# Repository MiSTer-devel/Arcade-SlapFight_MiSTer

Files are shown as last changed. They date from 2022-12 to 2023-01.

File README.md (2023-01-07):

<h1># SLAP FIGHT / ALCON</H1>
A big thank you to Neil Ward for providing a set of preliminary schematics and a diagnostic ROM.

Thank you to the following members of the MiSTer community: Boogermann, misterretrowolf, Sorgelig, Jotego, JimmyStones, Kitrinx & BirdyBro.

Slap Fight was developed by Toaplan and released by Taito in 1986. Slap Fight was known as ALCON (Alien League Of Cosmic Nations)

<h2>Compatible Platforms</h2>
<li>MiSTer FPGA</li>

<h2>Compatible Games</h2>
<blockquote>
<p dir="auto"><strong>ROMs NOT INCLUDED:</strong> By using this core you agree to provide your own roms.</p>
</blockquote>

<li>Slap Fight</li>
<li>Tiger Heli</li>
<li>Get Star</li>

<h2>Partially Working</h2>
<li>Performan</li>

<h2>Game Instructions:</h2>

	The year is 2059.  Aliens have overrun the planet.  The Allied League of Cosmic Nations, commonly called ALCON, have convened to combat this menace to the world.  ALCON has determined that a sole, experienced pilot, flying the experimental SW475 aircraft, must defend the world against certain destruction.

	YOU are the pilot that must fly the SW475 aircraft and defeat the aliens.

<h2>Maneuvers:</h2>

	Use the joystick to fly the SW475 over the terrain.
	Use 'Fire' button to shoot at enemies.
	Use 'Weapon Select' button to choose your weapons.
	The 'Weapon's Gauge' on the bottom of the screen shows which weapons can be used (the wording on the weapons turn yellow).
	Pick up starts to advance 'Weapon's Gauge'

<h2>Weapons available on the SW475:</h2>

	SPEED  - This will increase you flying speed
	SHOT   - Normal forward fire
	SIDE   - Right and Left fire
	WING   - Double, Triple and Quadruple fire power
	BOMB   - Wide range fire
	LASER  - Long range fire
	H. MIS - Homing missiles
	SHIELD - Indestructible against three hits

<h2>DIP Switch Settings:</h2>

	Cabinet Type       - Up-Right* ,Table
	Screen			   - Normal*, Invert
	Mode			   - Normal Game*, Screen Test Mode
	Demo Sounds		   - ON*, OFF 
	Coinage            - 1 Coin/1 Play*, 1 Coin/2 Play, 2 Coins/1 Play, 2 Coins/3 Play
	Difficulty         - A, B*, C, D
	Extend             - 30000 Every 100000*, 50000 Every 200000, 50000 Only, 100000 Only
	Fighter Count      - 1,2,3* & 5
	Dip Switch Display - OFF*, ON (show dip switch configuration) 

	*Factory Setting

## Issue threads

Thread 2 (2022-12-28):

Over hdmi has weird scaling issues and shimmering

Spazmoid1981, 2022-12-28:
Looks like the resolution is wrong or the video processing over hdmi is not correctly sized - also adding any video filter results in some weird shimmering over the screen

paulb-nl, 2022-12-31:
The `ce_pix` signal is generated incorrectly. Just output `pixel_clk` from slapcore.v and connect it directly to ce_pix and the `arcade_video` module will handle the rest.

https://github.com/MiSTer-devel/Arcade-SlapFight_MiSTer/blob/10bae8e3ea879105e4ef7865437a0482ff7a11ab/rtl/slapcore.v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

antongale, 2022-12-31:
> The `ce_pix` signal is generated incorrectly. Just output `pixel_clk` from slapcore.v and connect it directly to ce_pix and the `arcade_video` module will handle the rest.
>
> https://github.com/MiSTer-devel/Arcade-SlapFight_MiSTer/blob/10bae8e3ea879105e4ef7865437a0482ff7a11ab/rtl/slapcore.v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

Thank you for bringing this to my attention.  The core has been updated to bring the pixel_clk into arcade video.

Spazmoid1981, 2022-12-31:
Thanks guys - awesome - happy new year to all

Regards,
Michael Johnson
07976400758

On 31 Dec 2022, at 18:58, Anton Gale ***@***.***> wrote:

Closed #2<https://github.com/MiSTer-devel/Arcade-SlapFight_MiSTer/issues/2> as completed.

—
Reply to this email directly, view it on GitHub<https://github.com/MiSTer-devel/Arcade-SlapFight_MiSTer/issues/2#event-8132960947>, or unsubscribe<https://github.com/notifications/unsubscribe-auth/AUY442Q4PYKM4IUPOSNHM2TWQB63RANCNFSM6AAAAAATLTVGPQ>.
You are receiving this because you authored the thread.Message ID: ***@***.***>

Closed 2022-12-31.

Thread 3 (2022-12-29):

unable to flip screen for Tate mode when using CCW Tate orientation

konradpop, 2022-12-29:
flip screen option not available which is required when using a CCW tate screen

capitaineflam25, 2022-12-31:
Thanks for pointing the issue, my CRT is also CCW

antongale, 2022-12-31:
I am aware of the issue regarding the menu being missing.  An update will be released shortly.

antongale, 2022-12-31:
A new update has been pushed,  Rotation is only available over HDMI.  If you wish to flip the screen on a CRT use the DIP switch INVERT option.

Closed 2022-12-31.

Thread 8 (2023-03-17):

Slapfight sound issue

stiegis, 2023-03-17:
Don´t know if anyone experiences the same problem with the game

There is a weird sound issue going on i.e. sound only plays in mono and fades out after some time

Sound effects such as shooting etc. are not present sometimes

Also after the last update there is a missing line going through the sprites

Made a complete fresh setup in Mister but can reproduce these issues time and again

antongale, 2023-03-17:
Which update are you talking about?  Yesterdays?

stiegis, 2023-03-17:
Hello!

I am talking about the new rbf core - I made an update today and I noticed some graphics glitches in the sprites

The sound issue was BEFORE the new core update and has got nothing to do with it

P.S: I cannot be wrong about the sound issue because I compared it with the original pcb and the mister slap fight presentation

on you tube - perhaps it is my setup  it only plays in mono and somehow there are missing sounds (not polyphonic)

This is just an observation of mine - wonder if it is the same with other Mister users but I can only say that all the other

cores work perfectly fine on my mister setup. And that is the reason what makes it so weird

regards,

stiegis, 2023-03-17:
Oh I forgot something important - the graphics glitches were not present with the former rbf core

regards,
Alex

sorgelig, 2023-03-18:
Usually such issues happens when core has async clocks. Besides many async clocks, this core has several latches - another source of instability.
So core may have different kinds of issues in each build regardless what has been changed (like unrelated changes in framework affected the core work).

birdybro, 2023-03-19:
It looks like the core has a lot of async logic like sorgelig said. I looked into this after MikeS let me know. In one spot for sprite position, the output of a combinatorial block within a TTL module is being used as a clock for edge detection in a sequential block. These kinds of bugs will change from build to build without quartus giving any timing errors because so many of these are not clocked.

stiegis, 2023-03-20:
Hi!

Thanks sorgelig and birdybro

I highly appreciate your work

This was highly interesting - to find where those problems are located is probably much more difficult than to write the code

in the first place. On a hardware level when you try to fix a pcb you have to know the whole system - otherwise you will not

find the culprit. But with mister we are talking about a huge complex environment nearly unmanageable where so many

things can change. Its like comparing one drop of water with the ocean

regards

antongale, 2023-03-20:
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

Thank you for the insight, I'm still learning so I definitely don't take these comments as an insult.  I'll admit I don't know how to make this logic synchronous while retaining the rising edge detection.  The triggers are clocked with the pixel_clk.  Any insight would be helpful.

birdybro, 2023-03-20:
I'm not as far along as you are in the learning process for sure.

Given that your master clock is 36MHz, my personal way of writing the logic you laid out would be like this:

```sv
always @(posedge master_clk) begin
	if (SPR_LAT_VPOS) SPR_VPOS_D      <= SPRITE_RAM_D;	//S2_U1H
	if (SPR_LAT_INDX) SPR_IDX_D[7:0]  <= SPRITE_RAM_D;	//S2_U1J
	if (SPR_LAT_HPOS) SPR_HPOS_D[7:0] <= SPRITE_RAM_D;	//S2_U1L
	if (SPR_LAT_XDAT) begin 				//S2_U1K
		SPR_HPOS_D[8]	          <=SPRITE_RAM_D[0];
		SPR_IDX_D[9:8]	          <=SPRITE_RAM_D[7:6];
		SPR_EXT_D                 <=SPRITE_RAM_D;
	end
end
```

Not sure if this will work, doing this blind, compiling now...

Here test it out see if that resolves the issue:

[SlapFight_20230319.zip](https://github.com/MiSTer-devel/Arcade-SlapFight_MiSTer/files/11014155/SlapFight_20230319.zip)

If it did, then that's randomly what it was, but I'm just guessing.

stiegis, 2023-03-20:
Hello birdybro!

Thanks for giving this a go. I tried the last core 20230320 but did not solve the issue. Sound problem is still the same and the graphics are completely messed up now. Perhaps one has to adapt the mra file as well?

regards,
Alex

birdybro, 2023-03-20:
Nah, it's because I just blindly did this without knowing much about the core. The clocks I tied things to were probably wrong, and I probably didn't handle the uninitialized states correctly. Antongale knows the OG hardware better than anyone I think so he'll have to fix it.

antongale, 2023-03-20:
I'll fix it when I have time.  I'd rather roll back the changes and apply them, I'm aware of timing issues as I had them when originally developing the core.  Can you send me a screenshot as it will tell me exactly what the issue is.

birdybro, 2023-03-20:
There are other ways to address multiple asynchronous clocks, but it will have ot match the PCB logic that you are referencing to not break stuff the way I just did :P -

1. Use a small FIFO where crossed clock domains are occurring that might be causing improperly timed reads during writes --> https://github.com/MiSTer-devel/Arcade-TropicalAngel_MiSTer/blob/master/Arcade-TropicalAngel.sv#L344-L347 - this kind of thing might help with the sound issue if it's not already implemented.
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
2. Change some of these always blocks which use a non-clock in the sensitivity list to regular assign statements with ternaries to make them combinatorial where you are allowed to have an off-state for the signal default to 0 or something else. (e.g. `always @(posedge colour_copy) FG_PX_D[7:2]<=FG_RAMD[15:10];` --> `assign FG_PX_D[7:2]<= colour_copy ? FG_RAMD[15:10] : 6'd0`)
3. Convert inferred clocks (usually from dividers and counters) that are driving a latch (avoid latches anyways imo) or that is driving a register that is being used as a clock (in a sensitivity list of an always block)... into explicit clocks in the PLL wizard.
4. To avoid crossed clock domains in the first place, make sure that your clocks have even common division with one another, in the case of this core you have 36.0MHz, 37.93(actual 37.894736)MHz, 3.0MHz, 12.0MHz, and 72.0MHz. If you are driving logic off of outclk0/2/3/4 and you need to read/write data that is driven off of outclk1, then you will probably run into marginal timing issues.

stiegis, 2023-03-20:
Hello birdybro!

Oh my god. I thought that this stuff is not simple but this sounds to me like Chinese. Now I understand how deep this stuff goes - I don´t know how many scripts you need for a single core but to make it work at least 90% is a miracle at the end, You and the other programmers must be genius and one of a kind. If this works out fine otherwise its a good learning process.
But it is legit to point out where things can be improved
regards,

Alex

birdybro, 2023-03-20:
I'm not good at this stuff, I've only ported cores from MiST and fixed very minor things. I'm jealous of people like sorgelig and antongale who can build big complex systems up from very little.

antongale, 2023-03-21:
I've deleted the recent release SlapFight_20221231.rbf is still present and works.  I am looking into the timing issues now

antongale, 2023-03-21:
The line is now removed from the sprites.  I have played with the sound a little bit, but if anyone can help me figure out what I'm doing wrong with my JT49 implementation I'd appreciate it.  I've tried mimicking the 1942 core, but I get silence.

birdybro, 2023-03-21:
It looks like you disconnected the sound in the emu module:

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

birdybro, 2023-03-21:
Maybe @jotego would be willing to help.

jotego, 2023-03-21:
Here are my two cents.
It sounds that you need to re-design the core to make it synchronous. Just make JT49 use the same clock source as the CPU and generate a clock enable signal so the effective clock matches the one in the PCB. The clock enable signal should only be high for a single clock period.
If that doesn't make sense, I don't think I can help you.

antongale, 2023-03-21:
>  The clock enable signal should only be high for a single clock period. If that doesn't make sense, I don't think I can help you.

I think you've just given me an answer I've been searching for and looking at 'jtframe_cenxx.v' I understand what I've potentially been doing wrong.

antongale, 2023-03-22:
I've updated the clock generation to use logic almost identical to the jtframe_cen code.  I will update the code to be more synchronous, but the current build seems a lot more resilient to code changes.  The single clock period hint @jotego mentioned earlier was the key to getting jt49 to use the clk_en signal.

I still can't get the jtframe_fir part of the filter to work, so I'm still doing something wrong, but this definitely feels like progress.

jotego, 2023-03-22:
Exactly, it nots the frequency of the clock enable what matters per se, it's the number of cycles per second of the `clk & clk_en` signal. So jt49 was probably getting a much higher effective frequency than what you needed. I'm glad it's working for you now.

stiegis, 2023-03-22:
Hi!

Just tried out the new version and everything seems to work fine.

Sprite issues solved and music also ok

Thanks so much guys for working this out!! You are amazing

regards,

Alex

antongale, 2023-03-23:
Added Audio Pause to the core and utilized synchronous Z80 (T80s) for the audio CPU.  Sound glitching seems to be gone.

Closed 2023-03-23.

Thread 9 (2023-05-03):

Sound Error

harlock74, 2023-05-03:
Hi there,
When SlapFight boots up I get a Sound Error message. I have tried to press reset a few times but to no avail.
Many thanks!

birdybro, 2024-06-03:
Go into pause options and disable the pause on OSD, hit reset, and try again. The core pause seems unstable in it's current implementation.

harlock74, 2024-06-03:
Hi,
Thanks for your feedback. Unfortunately that didn't work for me.
It so weird that I don't have this issue on my second Mister setup.
Thanks anyways for your help.

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

christ776, 2024-07-23:
Hi, I'm having the same issue as well, and the workaround didn't work for me.

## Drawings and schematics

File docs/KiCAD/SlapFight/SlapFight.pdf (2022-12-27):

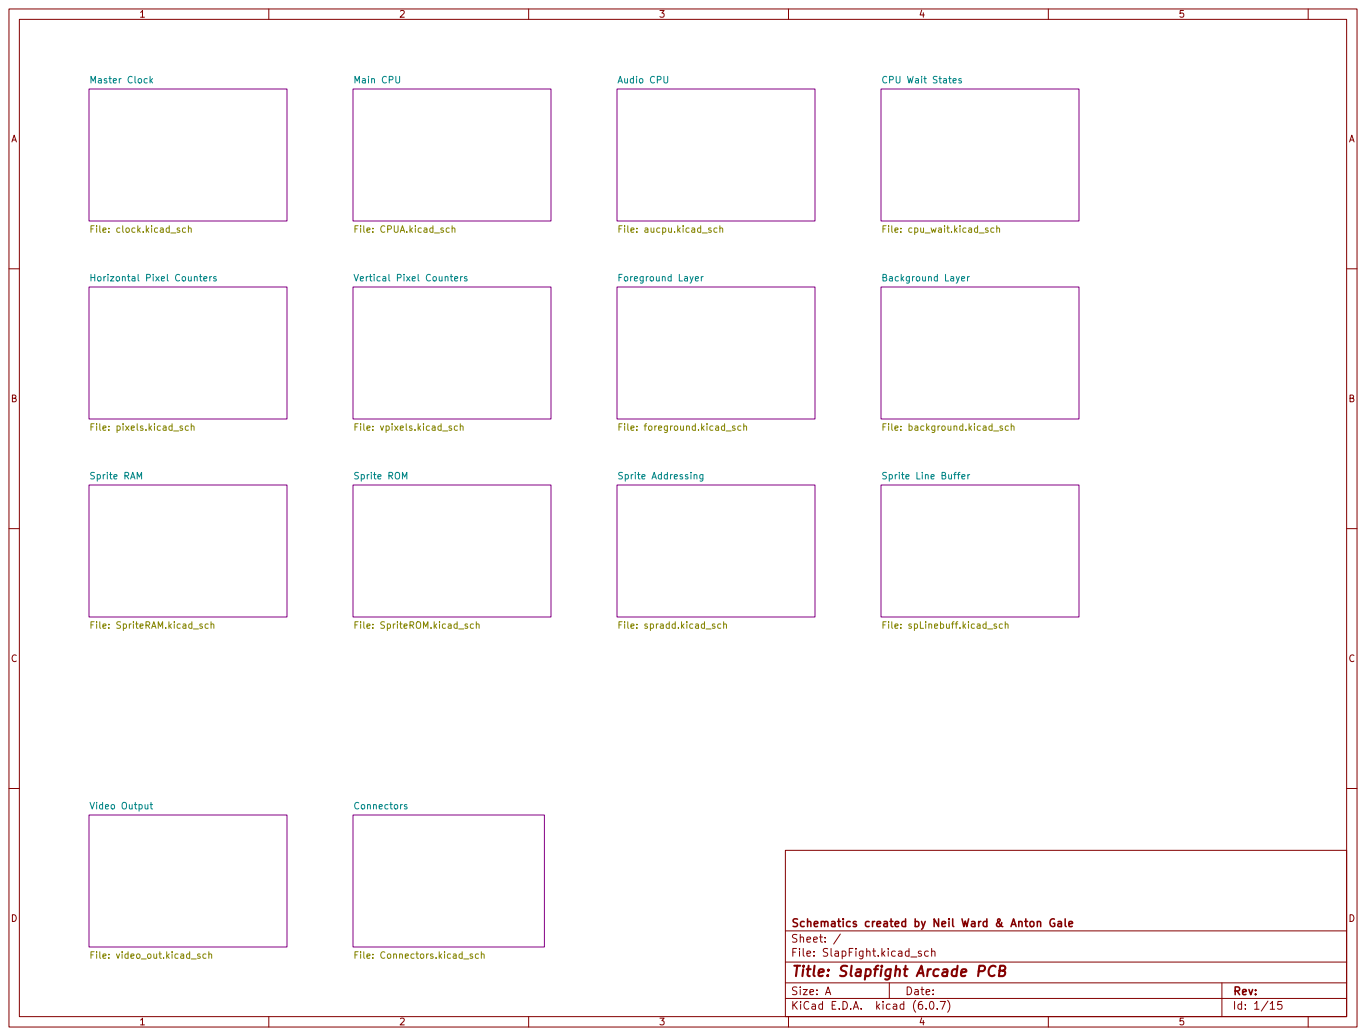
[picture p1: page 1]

CPU Wait States File: cpu_wait.kicad_sch Vertical Pixel Counters File: vpixels.kicad_sch

Horizontal Pixel Counters File: pixels.kicad_sch

File: SlapFight.kicad_sch Sheet: / Schematics created by Neil Ward & Anton Gale

Id: 1/15 Title: Slapfight Arcade PCB

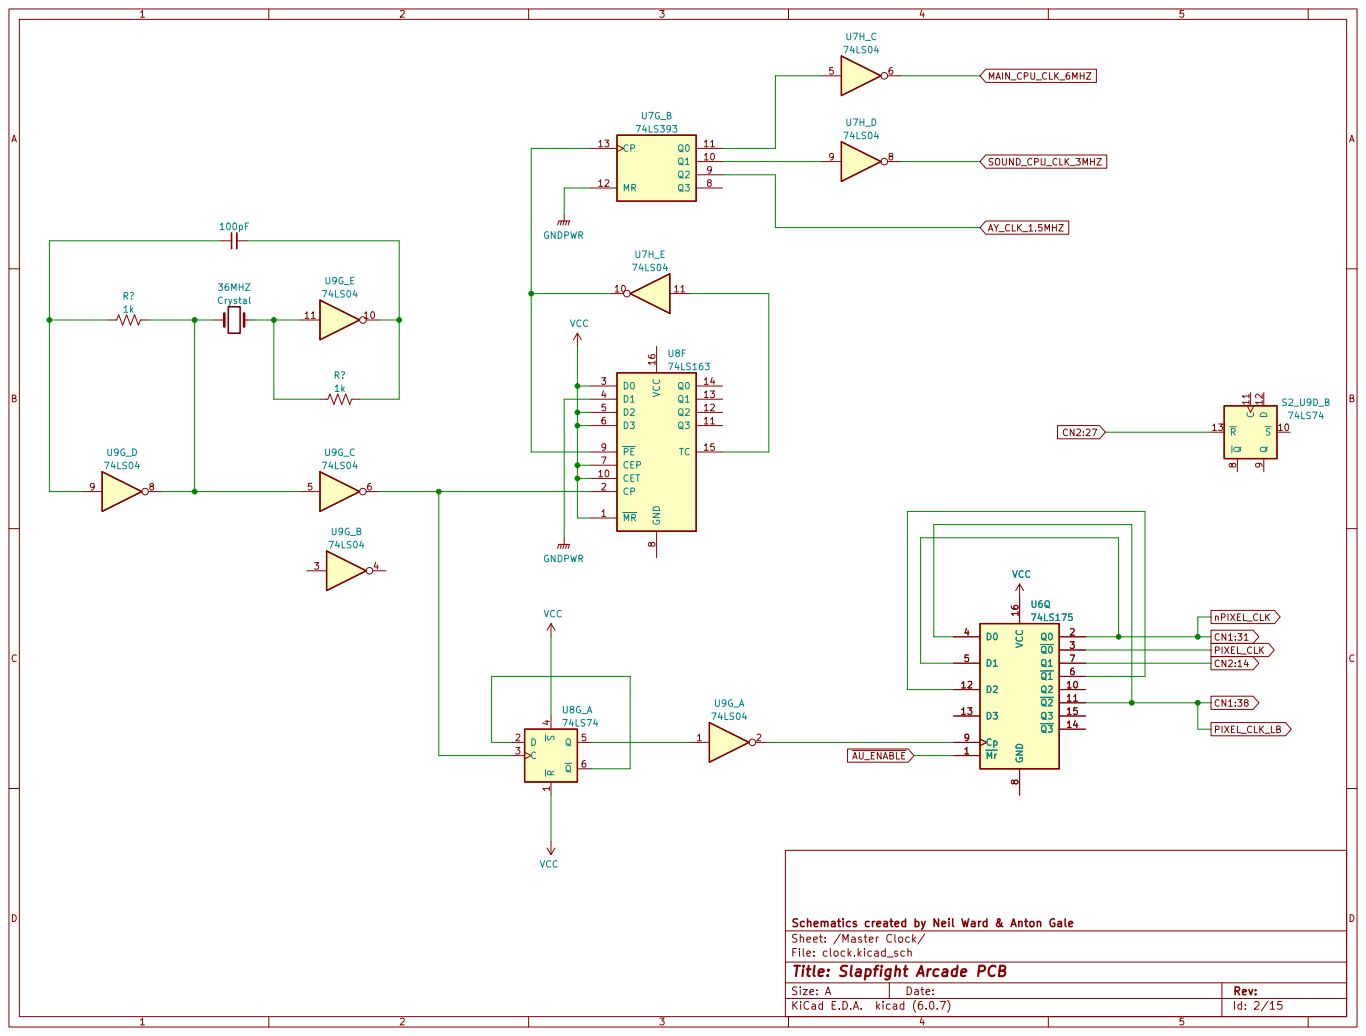
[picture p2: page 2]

File: clock.kicad_sch Sheet: /Master Clock/ Schematics created by Neil Ward & Anton Gale

Id: 2/15 Title: Slapfight Arcade PCB

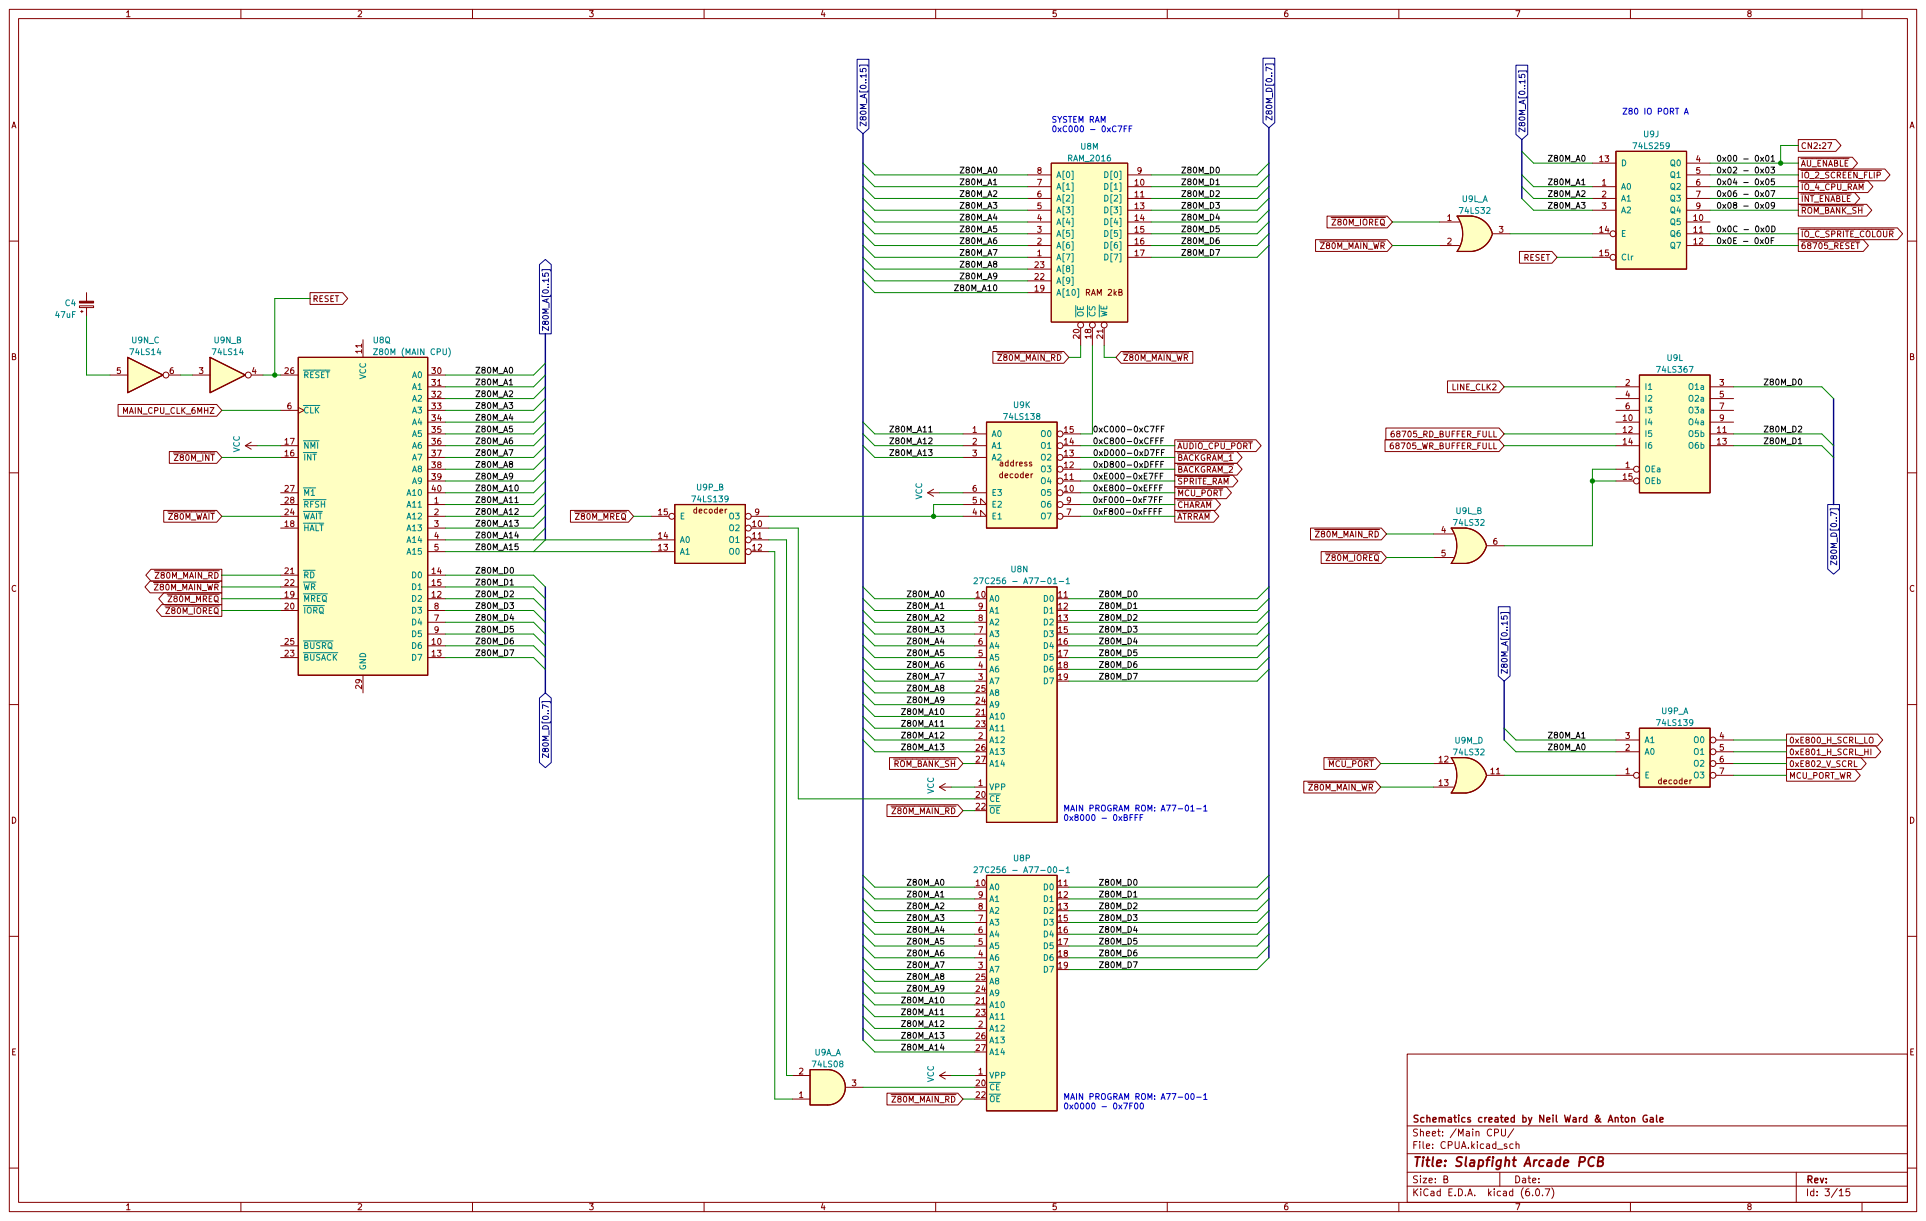
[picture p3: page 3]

Id: 3/15 Title: Slapfight Arcade PCB

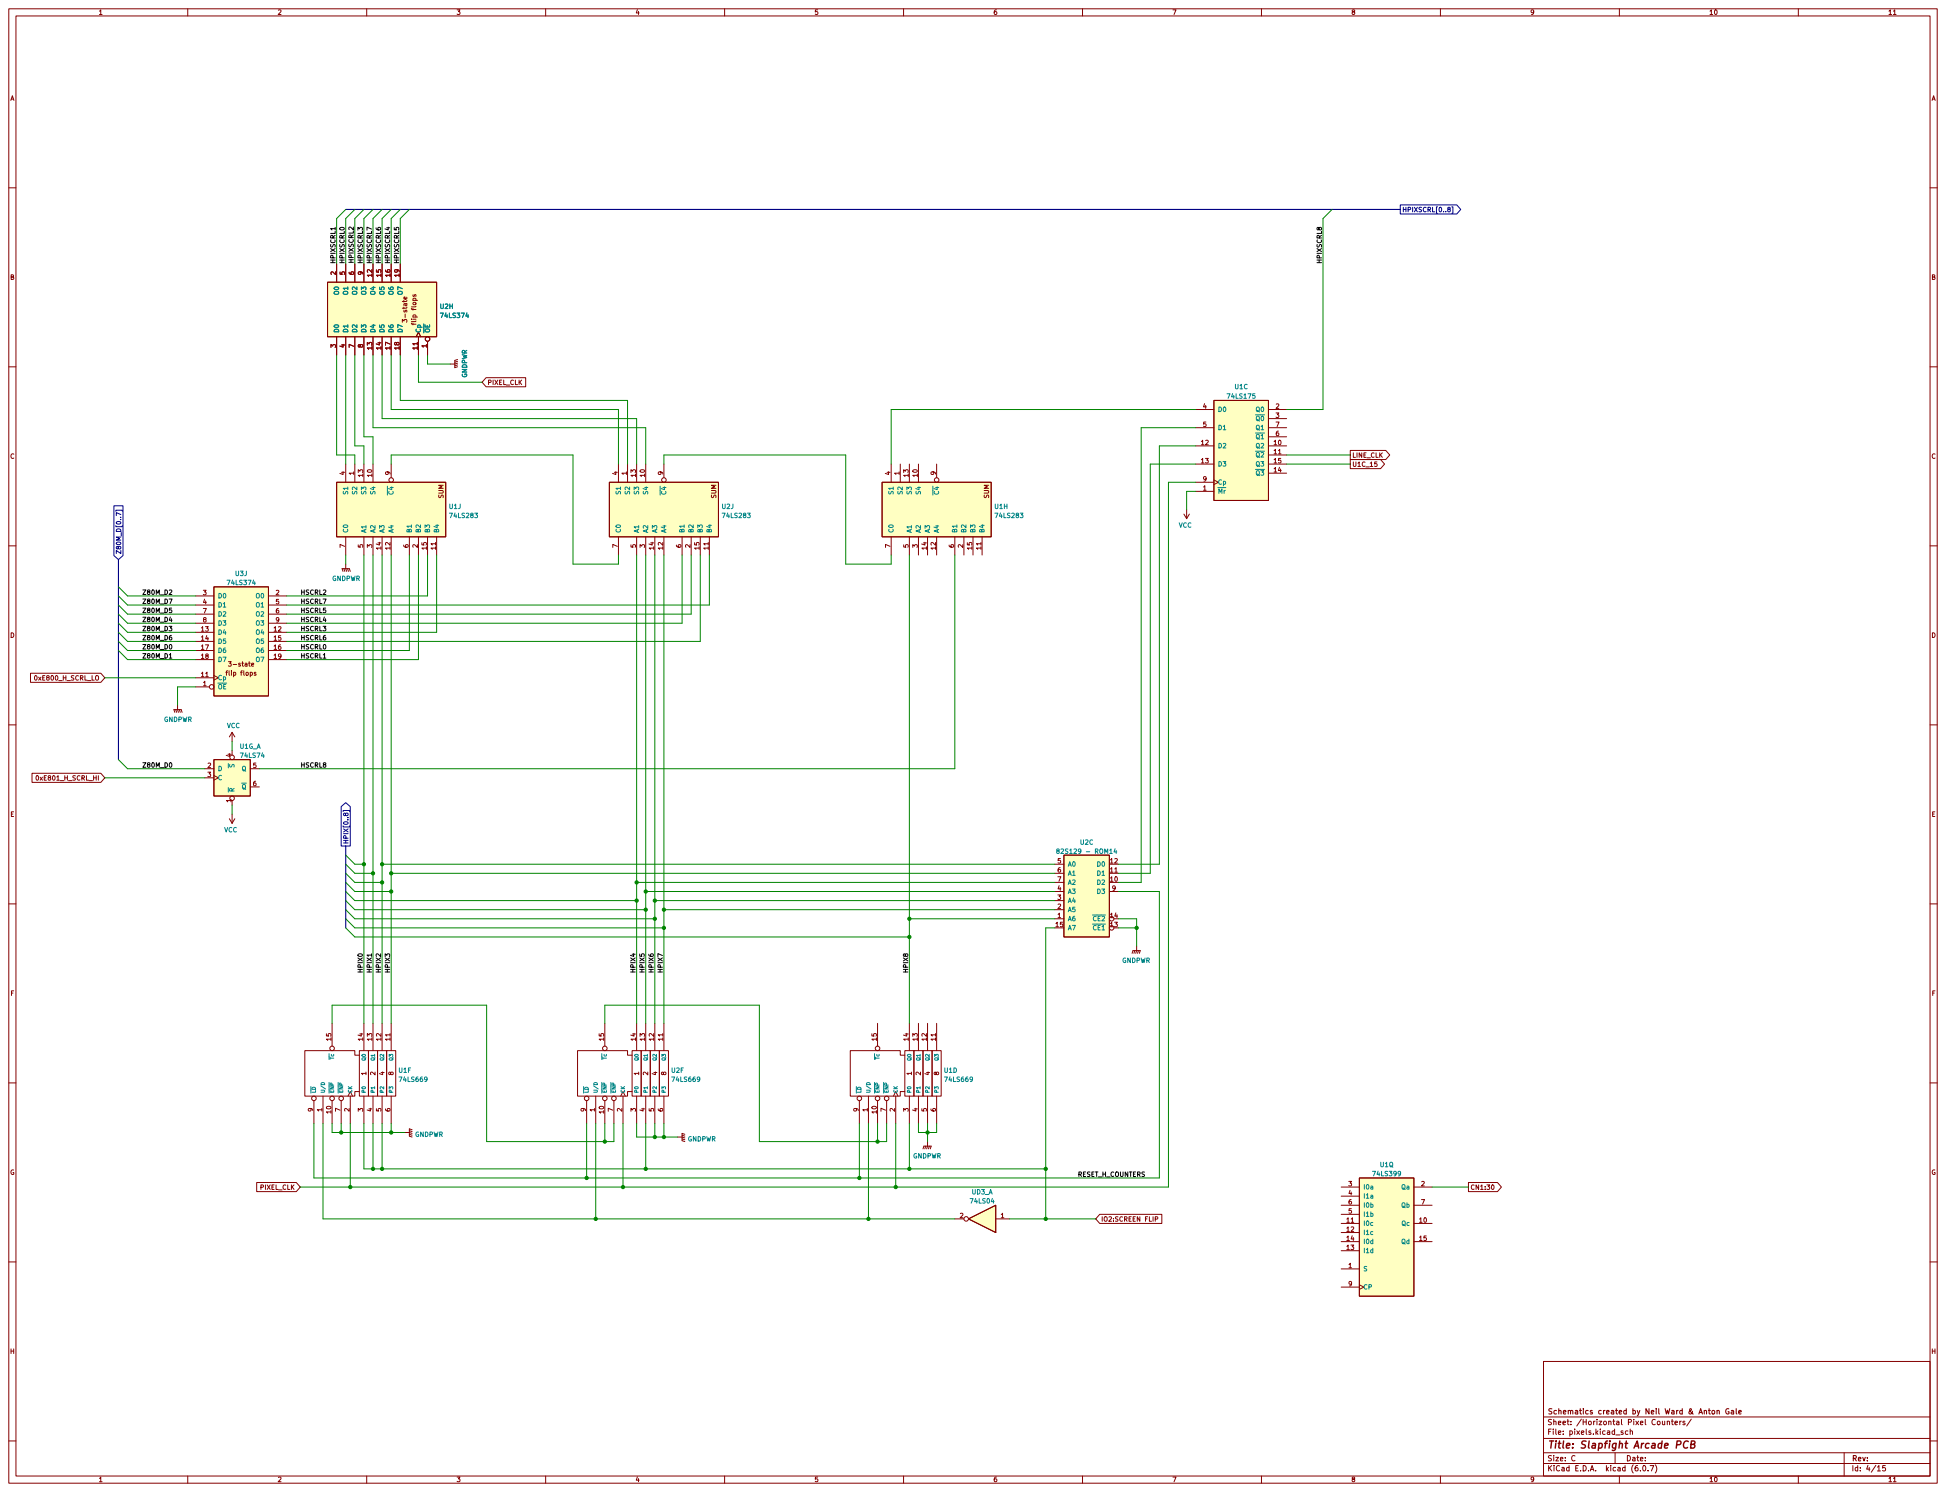
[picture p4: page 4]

File: pixels.kicad_sch Sheet: /Horizontal Pixel Counters/ Schematics created by Neil Ward & Anton Gale GNDPWRSUMS2

1 ~{ENP} 10 Q3 11 Q2 12 Q1 13 Q0 14 ~{Tc} 15 CK 2 P0 3 P1 4 P2 5 P3 6 ~{ENP} 7 ~{LD} 9 U1F

1 ~{ENP} 10 Q3 11 Q2 12 Q1 13 Q0 14 ~{Tc} 15 CK 2 P0 3 P1 4 P2 5 P3 6 ~{ENP} 7 ~{LD} 9 U2F

1 ~{ENP} 10 Q3 11 Q2 12 Q1 13 Q0 14 ~{Tc} 15 CK 2 P0 3 P1 4 P2 5 P3 6 ~{ENP} 7 ~{LD} 9 U1D

Id: 4/15 Title: Slapfight Arcade PCB

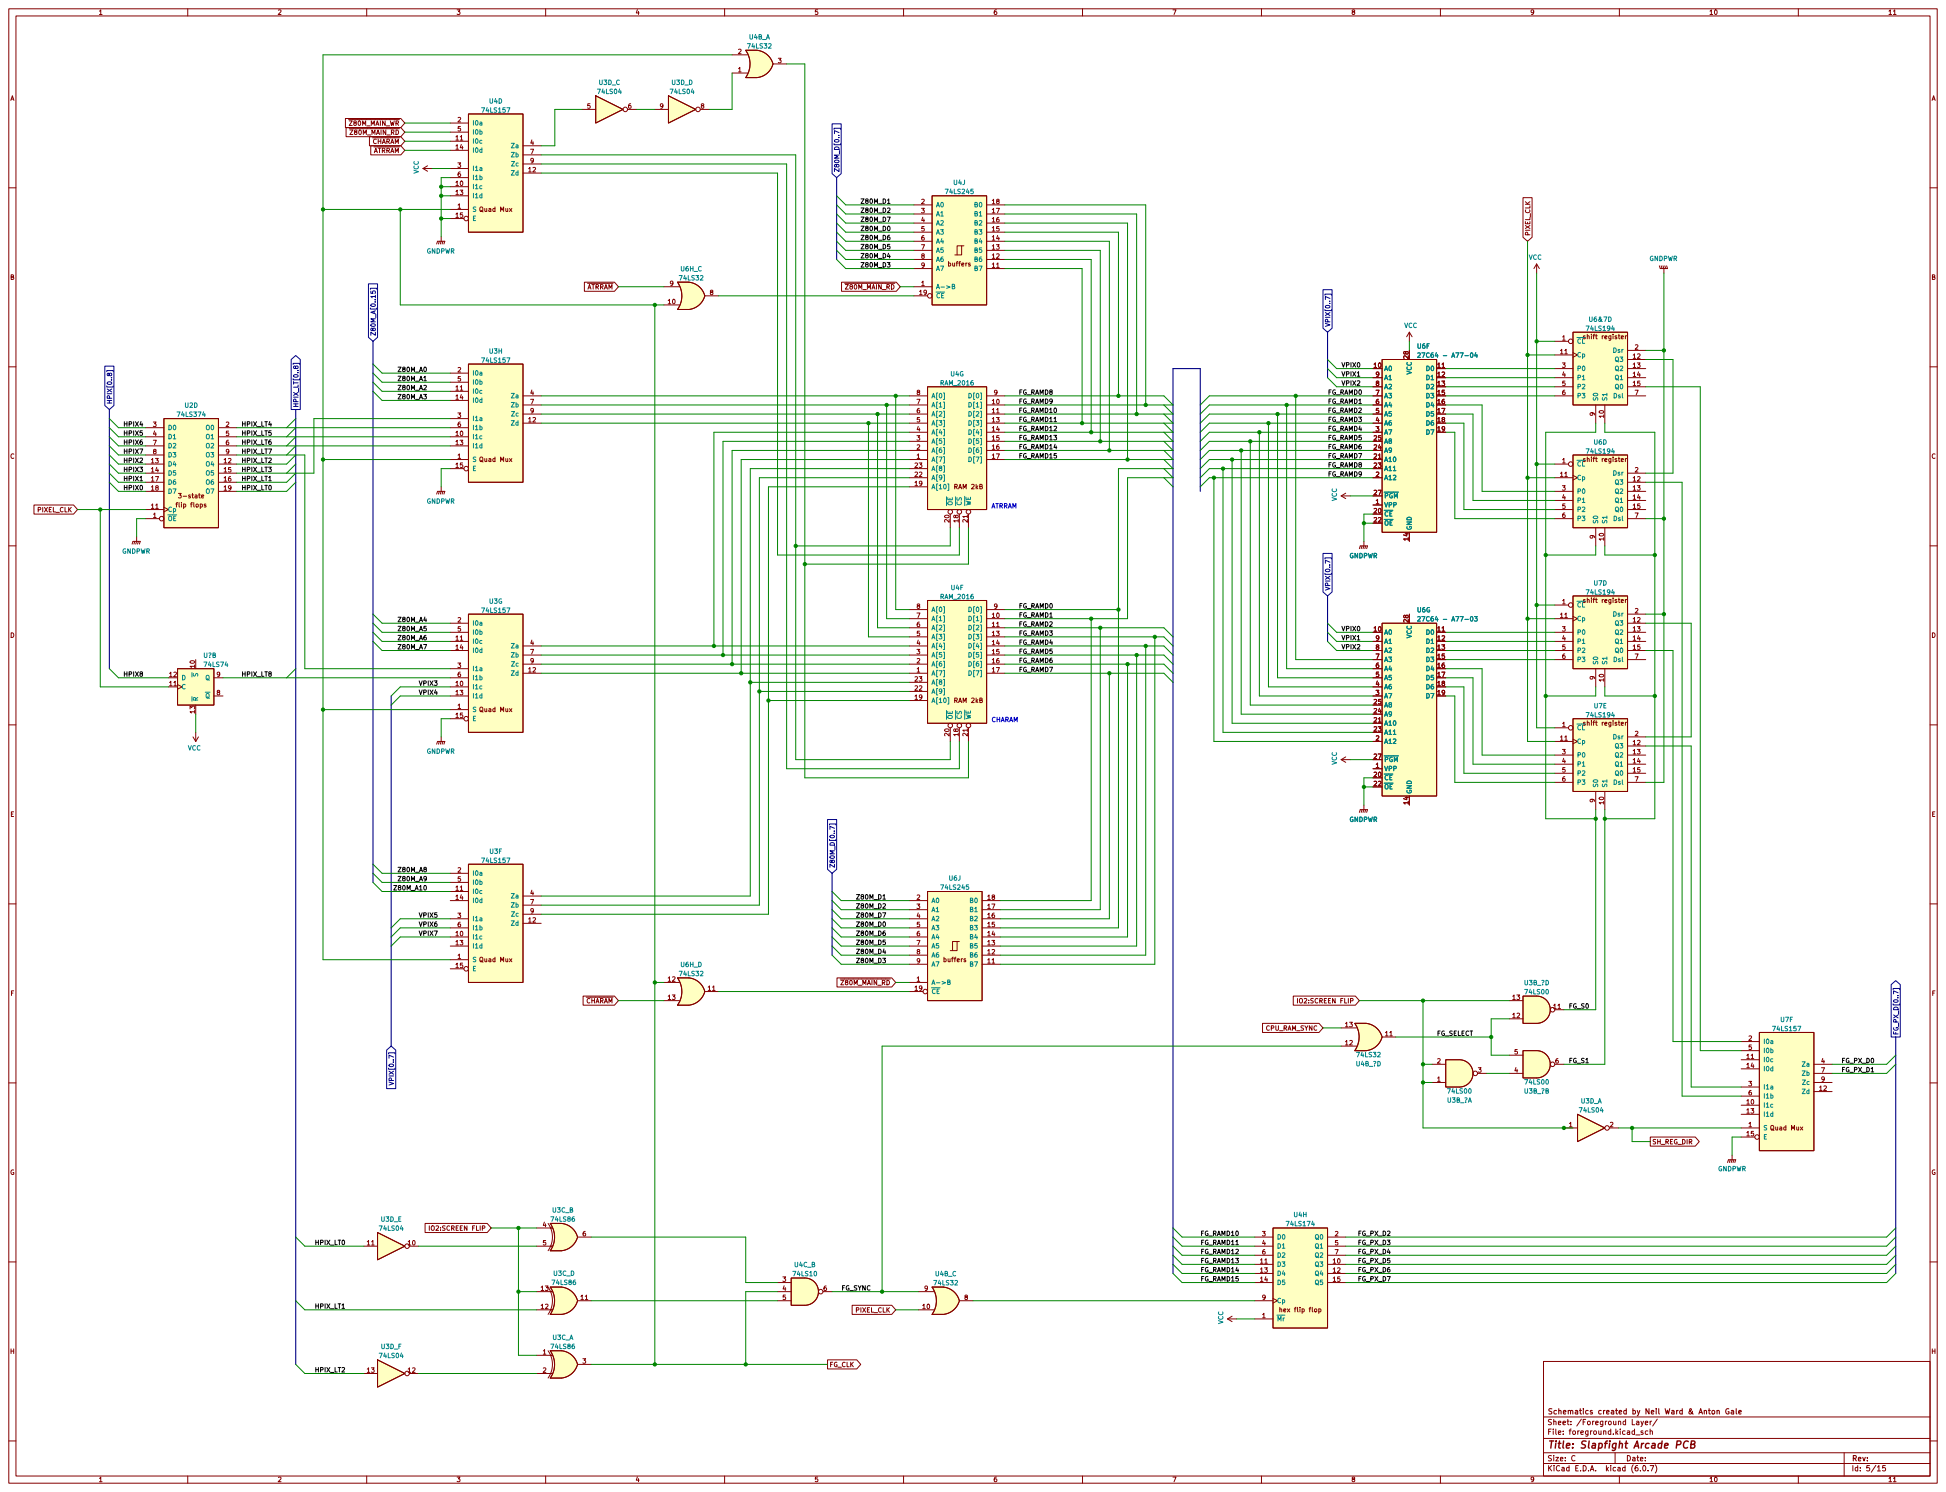
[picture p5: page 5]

12 Q2
13 Q1 14 Q0

Sheet: /Foreground Layer/
File: foreground.kicad_sch
Id: 5/15 Title: Slapfight Arcade PCB

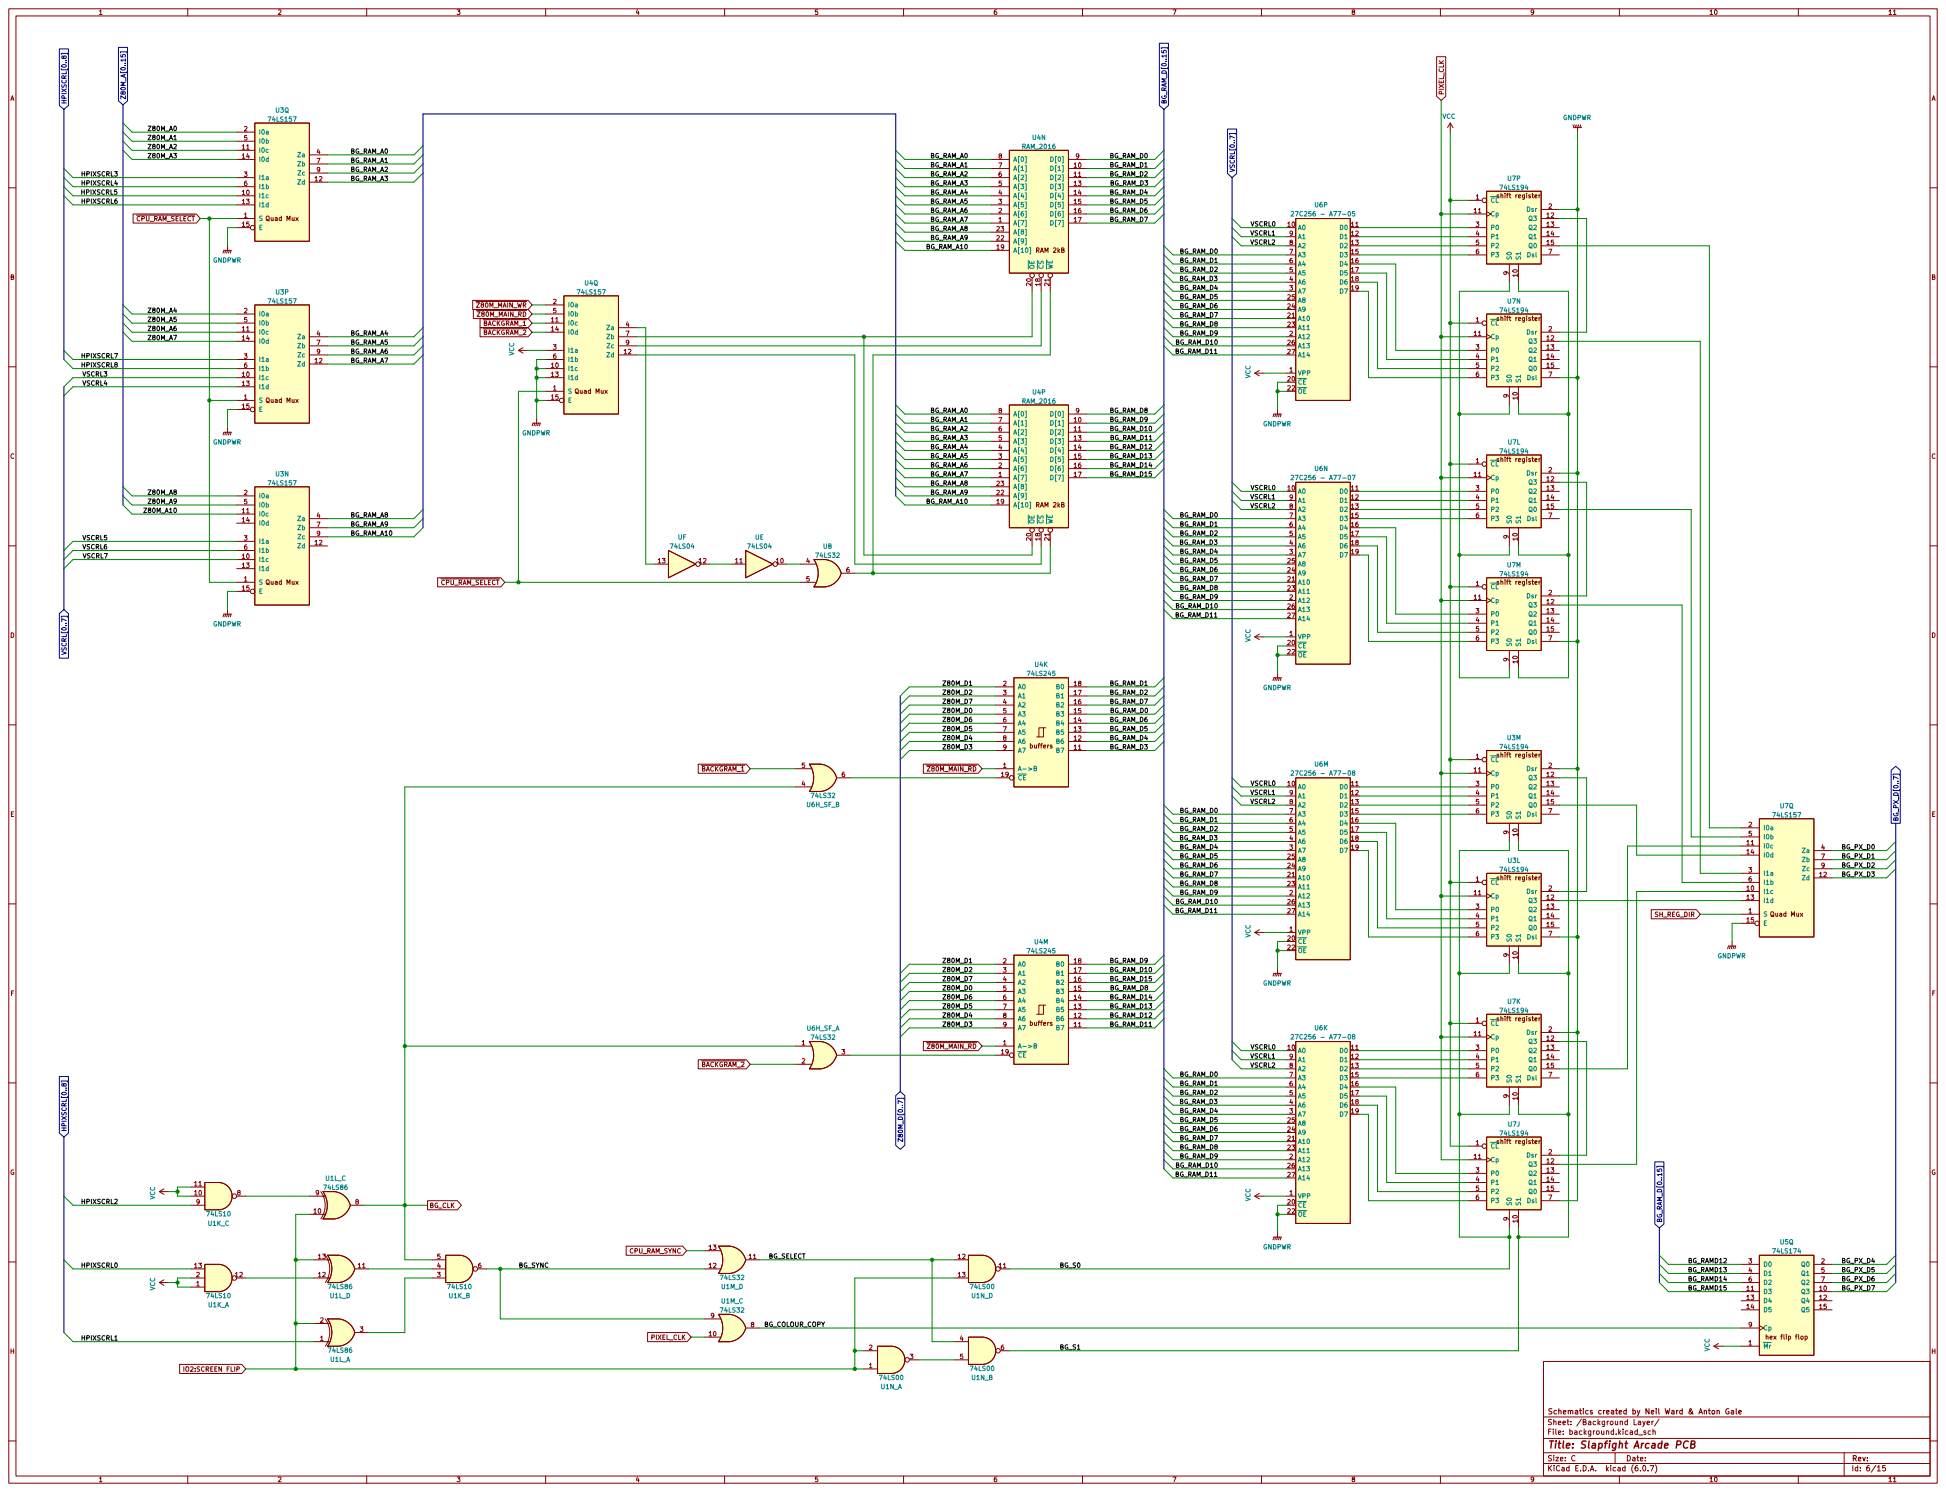
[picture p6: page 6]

Schematics created by Neil Ward & Anton Gale
Sheet: /Background Layer/
File: background.kicad_sch
Id: 6/15 Title: Slapfight Arcade PCB

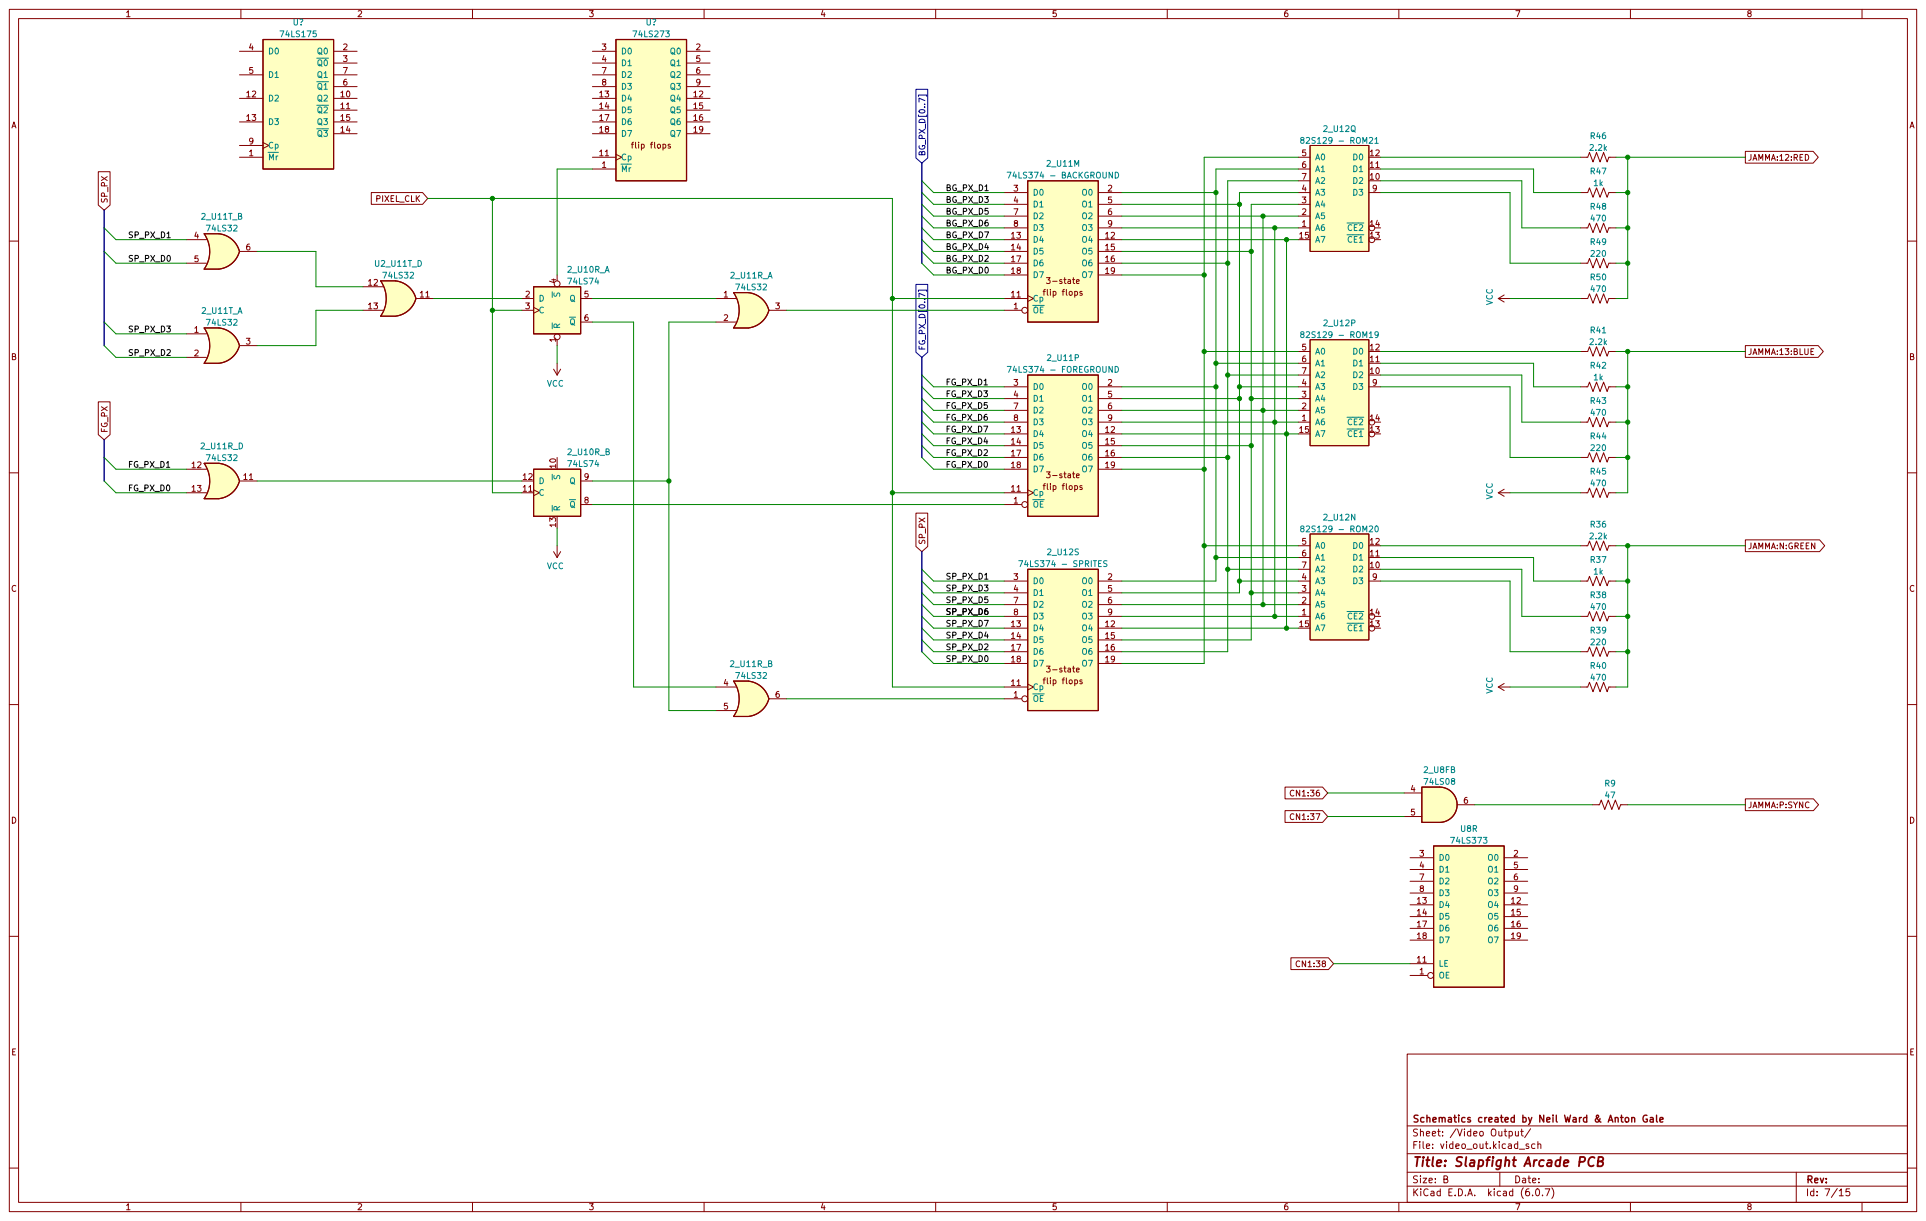
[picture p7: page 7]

Schematics created by Neil Ward & Anton Gale
Sheet: /Video Output/
File: video_out.kicad_sch
Id: 7/15 Title: Slapfight Arcade PCB

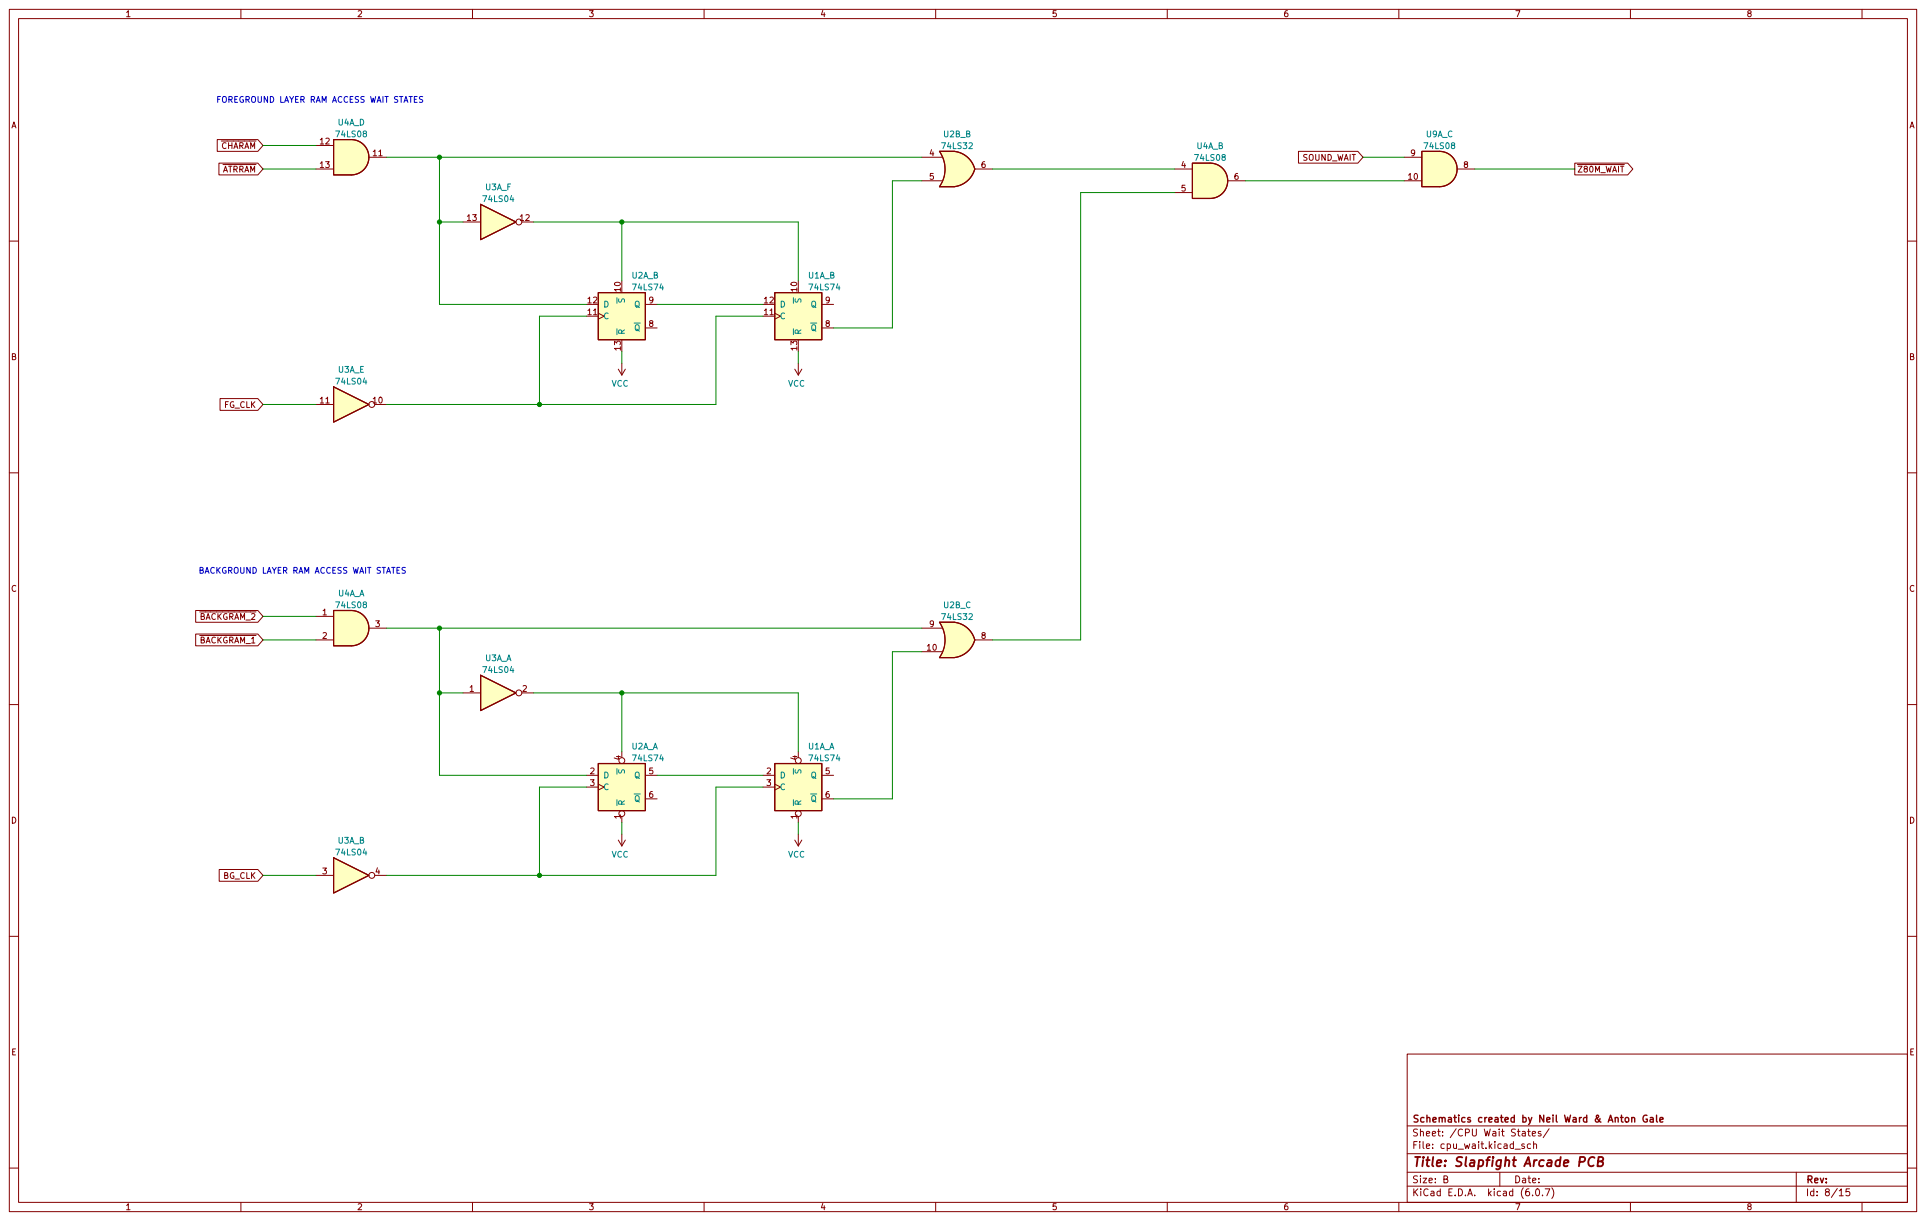
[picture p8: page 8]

~{ATRRAM} BACKGROUND LAYER RAM ACCESS WAIT STATES
74LS74 VCC

FOREGROUND LAYER RAM ACCESS WAIT STATES

File: cpu_wait.kicad_sch Sheet: /CPU Wait States/ Schematics created by Neil Ward & Anton Gale

Id: 8/15 Title: Slapfight Arcade PCB

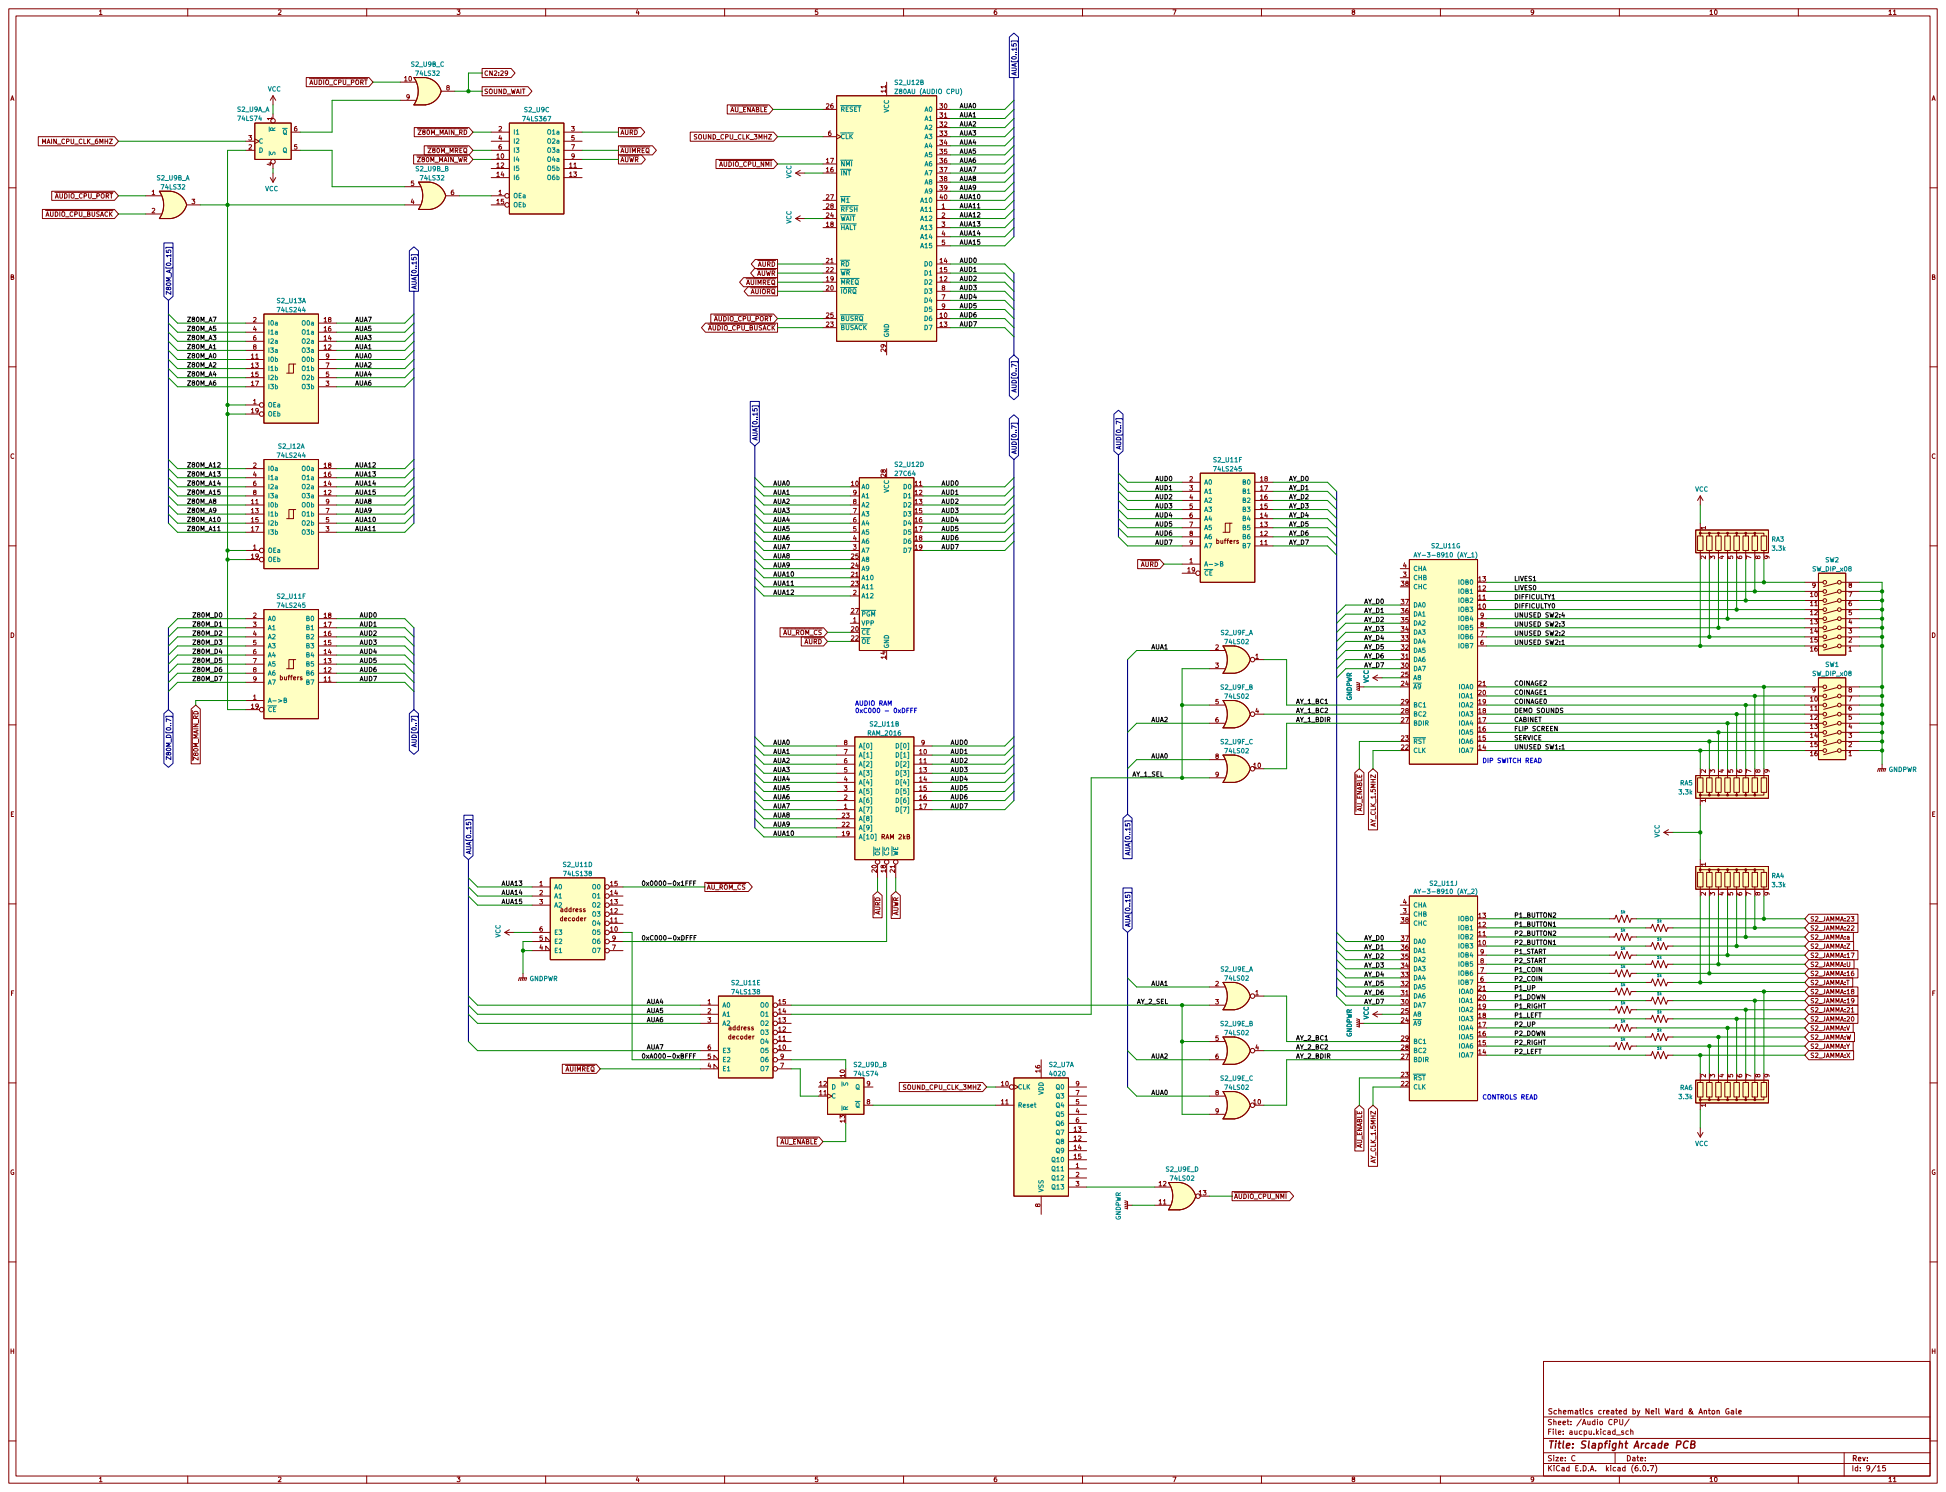
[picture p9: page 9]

CONTROLS READ VCC VCC GNDPWR GNDPWR
21 CLK

File: aucpu.kicad_sch Sheet: /Audio CPU/ Schematics created by Neil Ward & Anton Gale

Id: 9/15 Title: Slapfight Arcade PCB

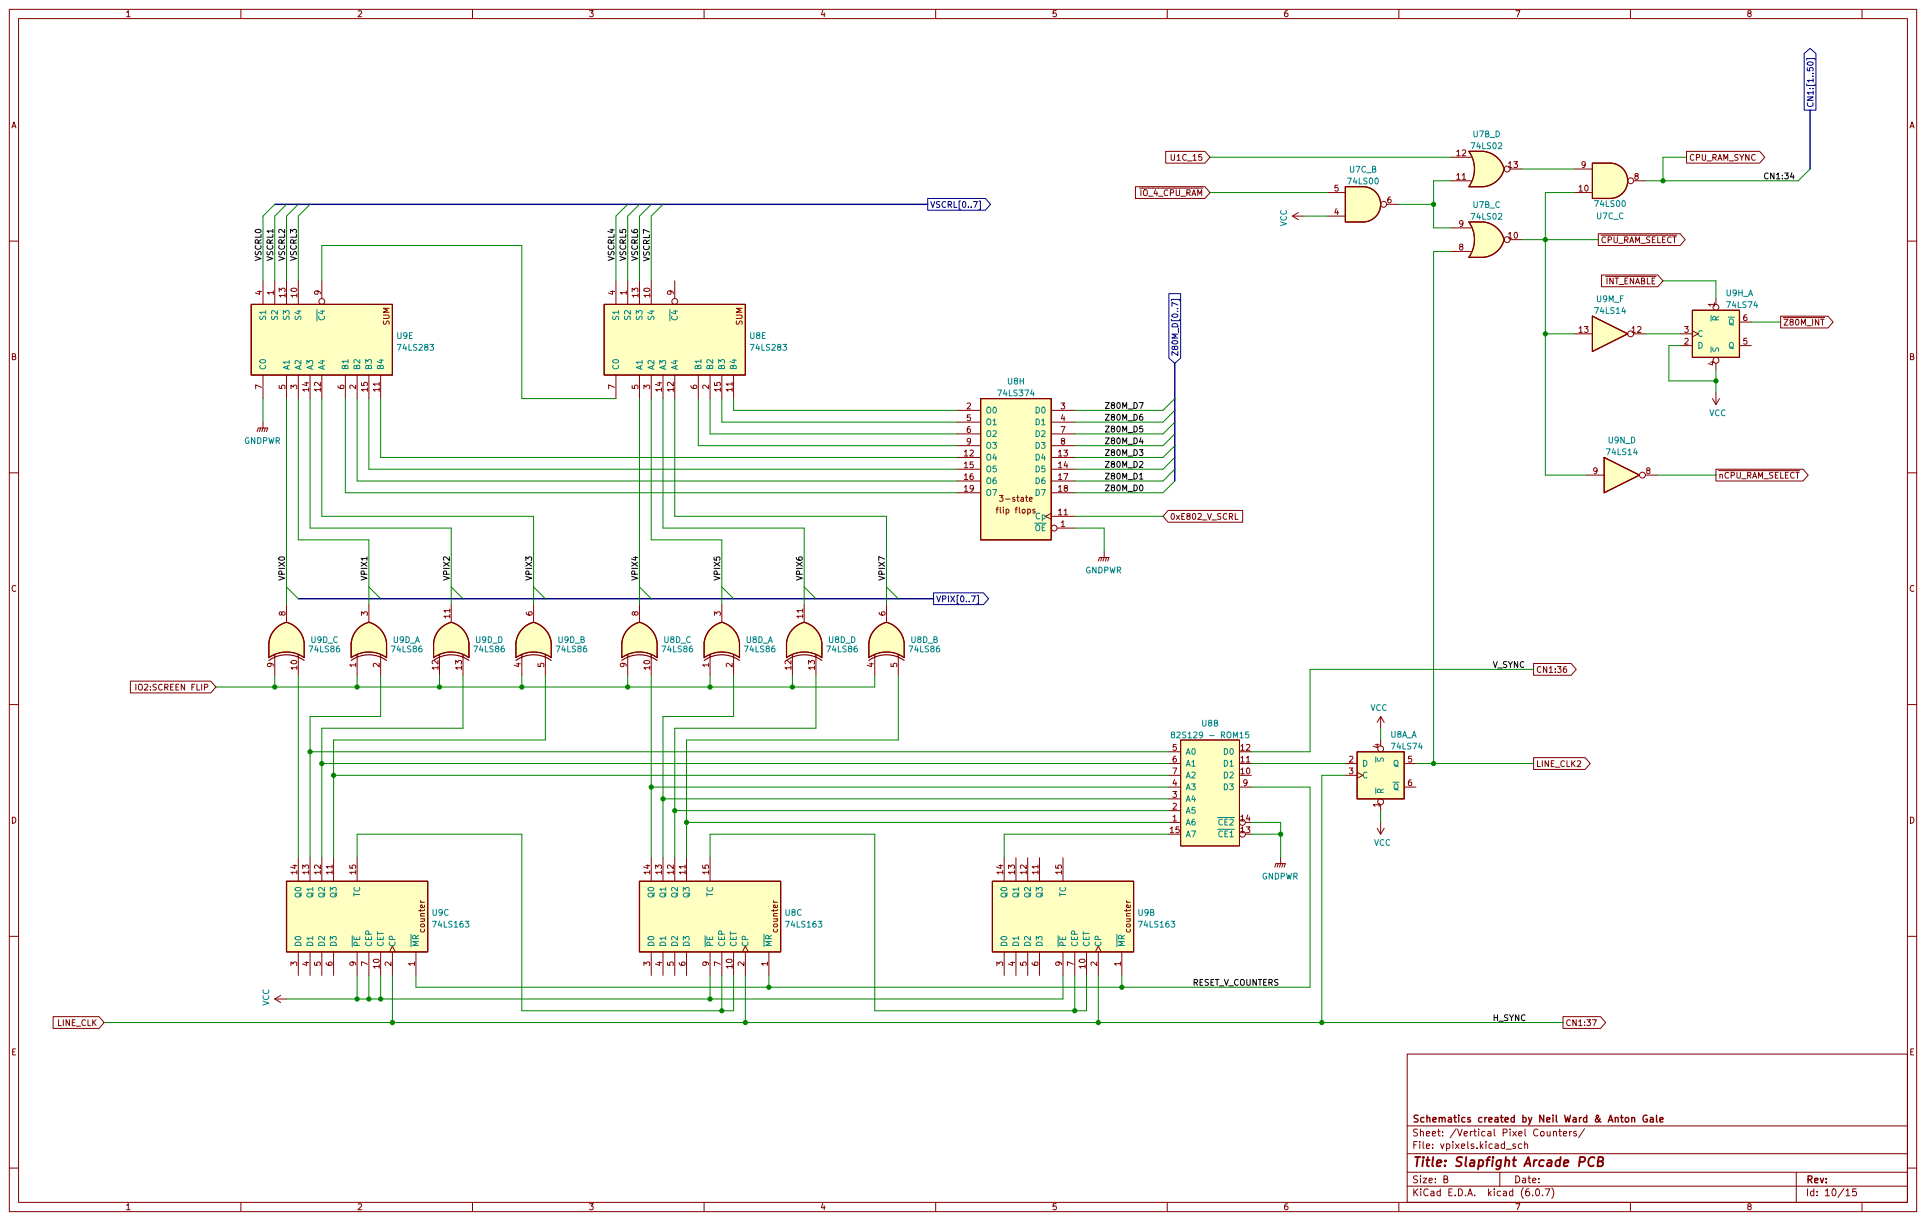
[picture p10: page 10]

Id: 10/15 Title: Slapfight Arcade PCB

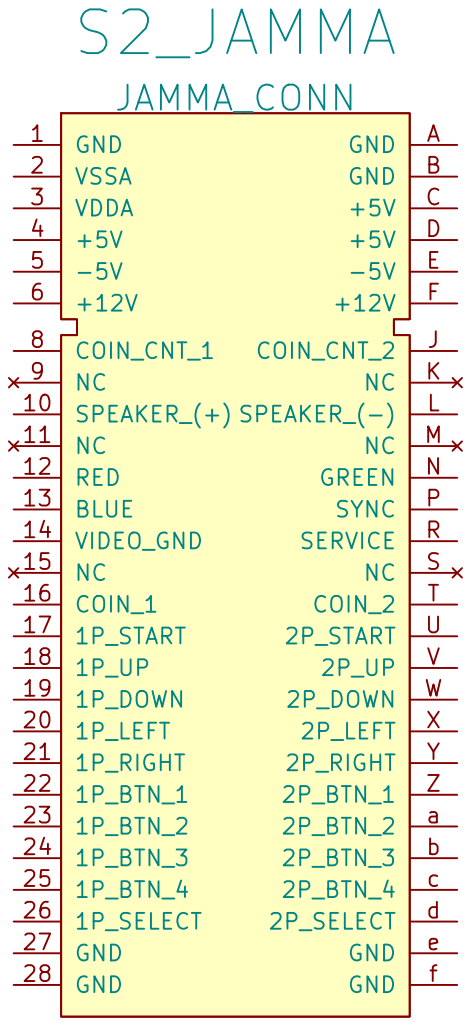
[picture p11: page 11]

File: Connectors.kicad_sch Sheet: /Connectors/ Schematics created by Neil Ward & Anton Gale

Id: 11/15 Title: Slapfight Arcade PCB

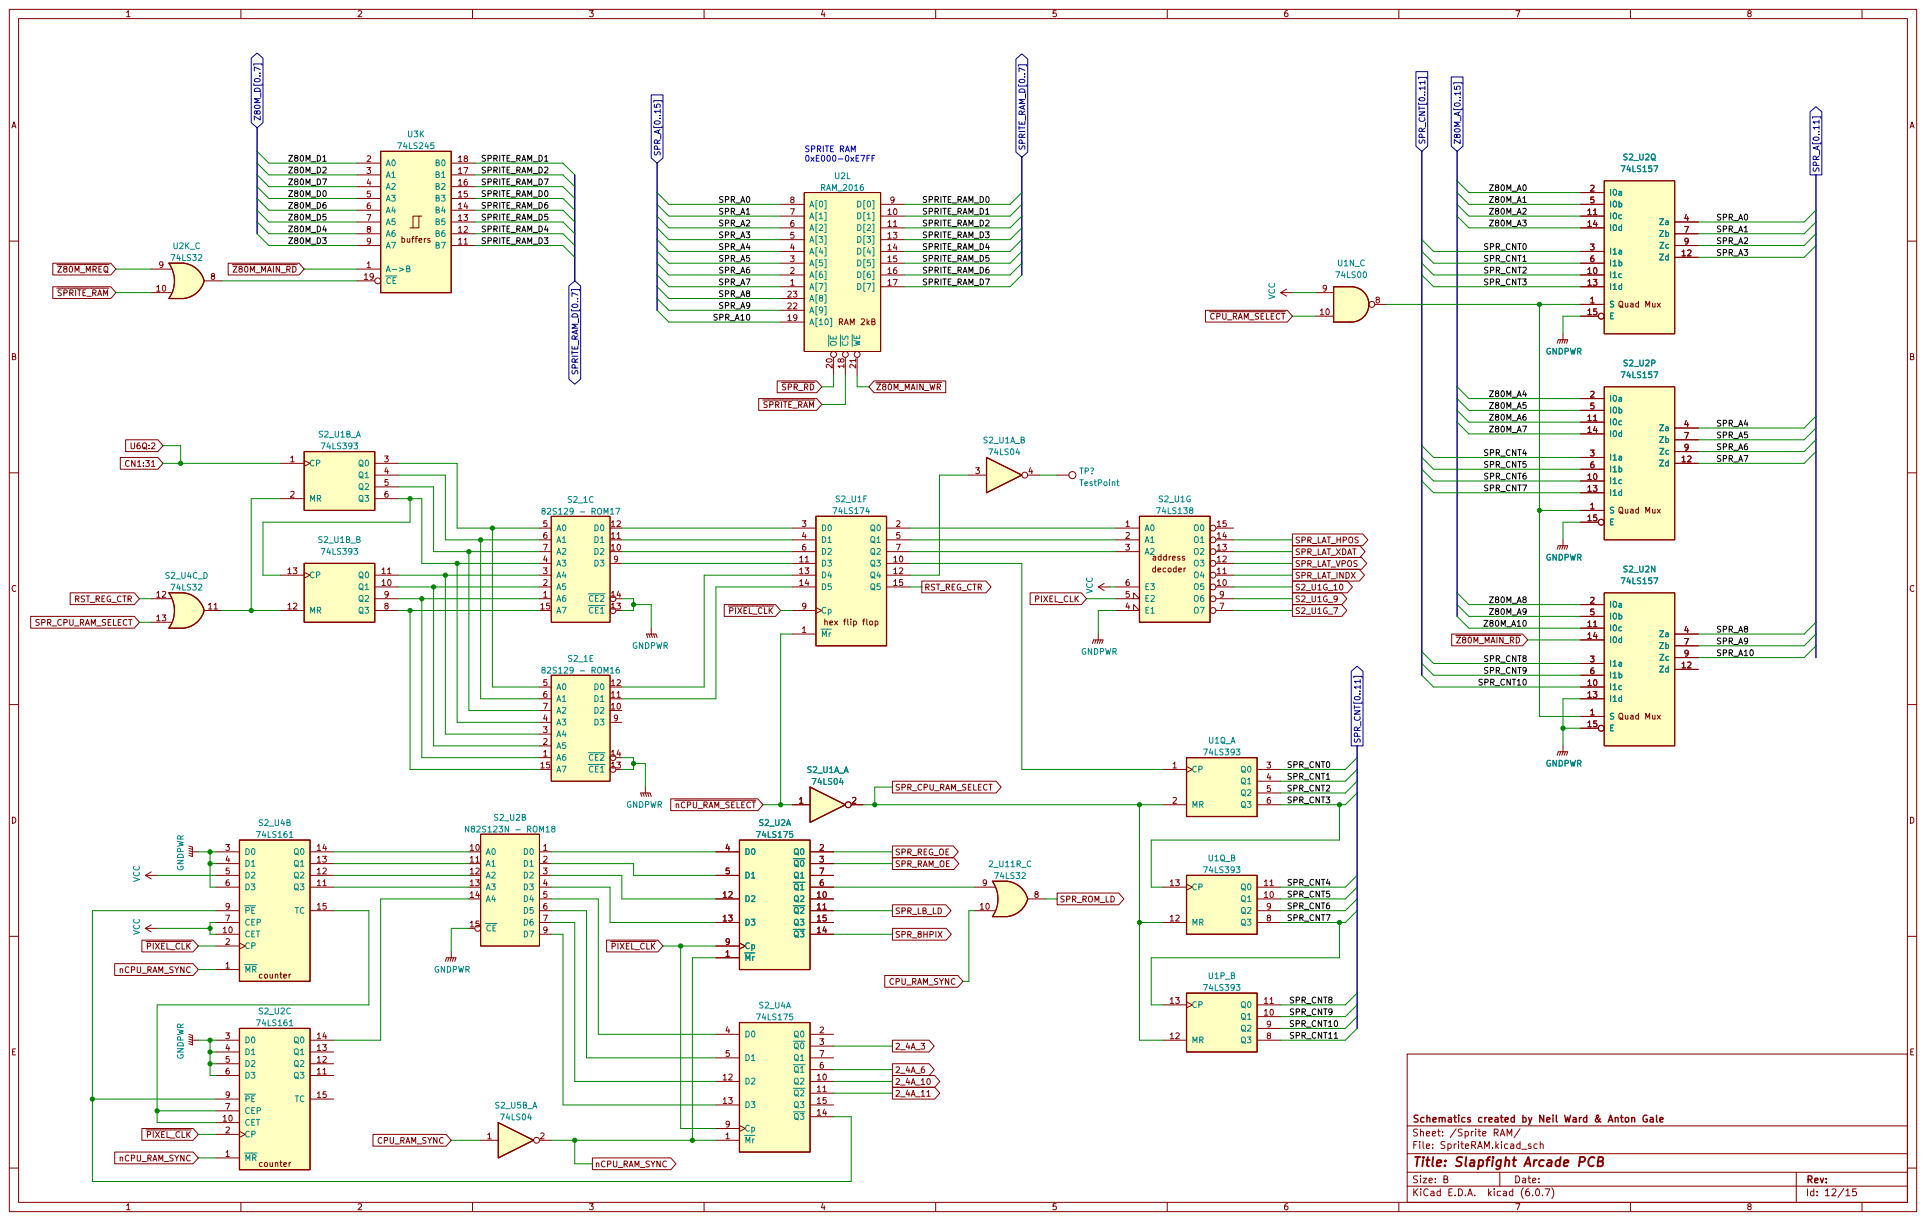
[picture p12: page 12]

Schematics created by Neil Ward & Anton Gale
Sheet: /Sprite RAM/
File: SpriteRAM.kicad_sch
Id: 12/15 Title: Slapfight Arcade PCB


Sheet: /Sprite ROM/
File: SpriteROM.kicad_sch
Id: 13/15 Title: Slapfight Arcade PCB


SPRITE RAM ADDRESS GENERATION

Schematics created by Neil Ward & Anton Gale
Sheet: /Sprite Addressing/
File: spradd.kicad_sch
Id: 14/15 Title: Slapfight Arcade PCB


Schematics created by Neil Ward & Anton Gale
Sheet: /Sprite Line Buffer/
File: spLinebuff.kicad_sch
Id: 15/15 Title: Slapfight Arcade PCB

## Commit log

2022-12-26 new file: .gitattributes new file: .gitignore new file: Arcade-SlapFight.old.sdc new file: Arcade-SlapFight.out.sdc new file: Arcade-SlapFight.qpf new file: Arcade-SlapFight.qsf new file: Arcade-Slap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
    [CPUA.kicad_sch, Connectors.kicad_sch, SlapFight.kicad_sch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]
2022-12-27 Updated missing IC locations in schematic
2022-12-28 Pre combo board
    [SlapFight.kicad_sch, aucpu.kicad_sch, cpu_wait.kicad_sch]
2023-03-26 Slapfight 60Hz Beta
